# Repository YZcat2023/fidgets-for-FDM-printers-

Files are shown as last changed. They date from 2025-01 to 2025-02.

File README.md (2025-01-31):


<!-- PROJECT SHIELDS -->

<!-- PROJECT LOGO -->
<br />
<div align="center">
  <a href="https://github.com/YZcat2023/MKPSupport/blob/main/">
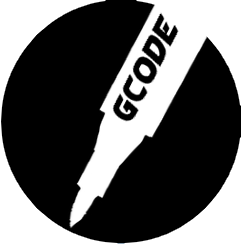
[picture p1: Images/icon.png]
    
  </a>

  <h3 align="center">MKP Support</h3>

  <p align="center">
    Better supports for FDM prints
    <br />
    <a href="https://github.com/YZcat2023/MKPSupport/blob/main/MKP%20Manual.pdf"><strong>Download MKP Manual »</strong></a>
    <br />
    <br />
  </p>
</div>

<!-- TABLE OF CONTENTS -->
<details>
  <summary>Table of Contents</summary>
  <ol>
    <li>
      <a href="#about-the-project">About The Project</a>
      <ul>
        <li><a href="#built-with">Built With</a></li>
      </ul>
    </li>
    <li><a href="#illustration">Illustration</a></li>
    <li>
      <a href="#getting-started">Getting Started</a>
      </ul>
    </li>
    <li><a href="#roadmap">Roadmap</a></li>
    <li><a href="#contributing">Contributing</a></li>
    <li><a href="#license">License</a></li>
    <li><a href="#contact">Contact</a></li>
    <li><a href="#acknowledgments">Acknowledgments</a></li>
  </ol>
</details>

<!-- ABOUT THE PROJECT -->
## About The Project
When printing parts using FDM 3D printers, supports often pose a significant challenge. They can be difficult to remove, leaving the surface of the part uneven. Therefore, reducing the layer adhesion between the support layers and the part could be a viable solution. That's why we're here—to introduce MKP Support, which delivers better results: the support surface is smooth, flat, and non-sticky, with no color difference from the main body of the part. Thanks to the incorporated function of ironing the support surface, the results may even surpass those achieved with water-soluble supports. With just four magnets, two screws, a bottle of liquid glue, and other necessary items, you can upgrade your printer. It can be run as a post-processing program in OrcaSlicer. Simply press the button, just like in the previous workflow!
<!-- FDM3D打印零件时，支撑总是一个让人头疼的问题。它们有时很难移除，移除后的零件表面也不太平整。那么，降低支撑层与零件间的层粘也许是一个好主意？试试看MKP Support吧，它能实现相当好的效果：
支撑面光滑平整不粘手，且颜色与零件主体没有区别。由于加入了熨烫支撑面的功能，也许效果比使用水溶支撑还要好。只需要四块磁铁，两个螺丝，一瓶液体胶等等，您就可以升级您的打印机。
我找来了一只马克笔涂抹支撑面，结果相当成功。接触面看上去很平滑。不过，马克笔的方案并不十分令人满意：它似乎不能在CoreXY机器上工作。于是我找来了一些 gluepen refills("点点胶替芯" in Chinese）。胶水是透明的，因此接触面效果更加好了。不过，它似乎很容易就用完了。所以我设计了一个零件用来储存胶水，并且重新编写了程序。 -->

<!-- 使用MKP Support,可以减少时间与材料的浪费
使用MKP Support,可以提高接触面的表面效果
使用MKP Support,可以提高打印的成功率 -->
Here's why:
* Using MKP Support can reduce waste of time and materials.
* Using MKP Support can enhance the surface finish of the contact area.
* Using MKP Support can increase the success rate of printing.

### Built With


  

## Illustration
Here are some printed samples. More photos may come, stay tuned!
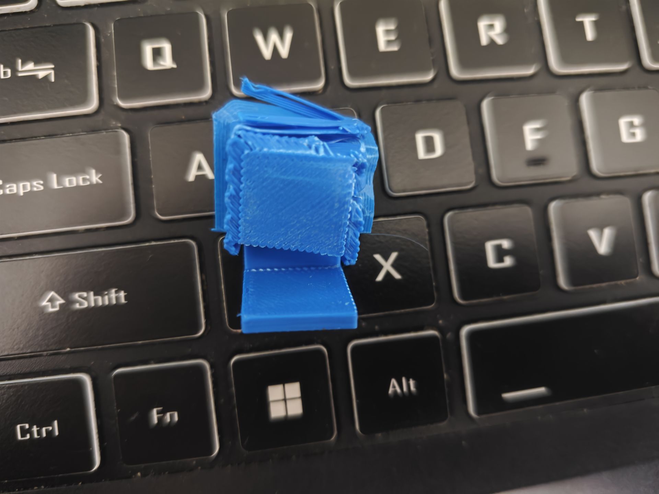
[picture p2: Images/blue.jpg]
Descriptive Alt Text


<p align="right">(<a href="#readme-top">back to top</a>)</p>

<!-- GETTING STARTED -->
## Getting Started
For more details, please refer to MKP Manual.pdf.
1.	Have some gluepen refills("点点胶替芯" in Chinese）and one bottle of liquid glue.
Get two M2.5*5 screws and four magnets with a diameter of 4mm and a thickness of 1.5mm.
2.	Download the 3D printing models provided in the folder and print them. Assemble the printed parts and install them in a proper location on your 3D printer. You may need some modification in order to suit your own printer. 
3.	Configure Settings: Run the software and fill in the required information in the dialog box. It will generate a config file. Then copy the path of MKP3.0.exe and go to your Orca Slicer settings, paste it and change several settings. If you’re using printers shipped with klipper firmware, then creating several macro is prefered.
4.	Click Slicing button and enjoy. You can also place your Gcode file in the same folder as this software and start the software. 

<!-- ROADMAP -->
## Roadmap

- [x] Ironing support interfaces option
- [x] Add MKP Manual.pdf
- [ ] Add multi-color support
- [ ] Multi-language Support
    - [ ] English

See the [open issues](https://github.com/YZcat2023/MKPSupport/issues) for a full list of proposed features (and known issues).

<p align="right">(<a href="#readme-top">back to top</a>)</p>

<!-- CONTRIBUTING -->
## Contributing
Currently, there are no other contributors on this project. We welcome anyone who would like to join!

<!-- LICENSE -->
## License

Distributed under the Unlicense License. See `LICENSE.txt` for more information.

<p align="right">(<a href="#readme-top">back to top</a>)</p>

<!-- CONTACT -->
## Contact
Jhmodel01@outlook.com
Project Link: [https://github.com/YZcat2023/MKPSupport](https://github.com/YZcat2023/MKPSupport)

<p align="right">(<a href="#readme-top">back to top</a>)</p>

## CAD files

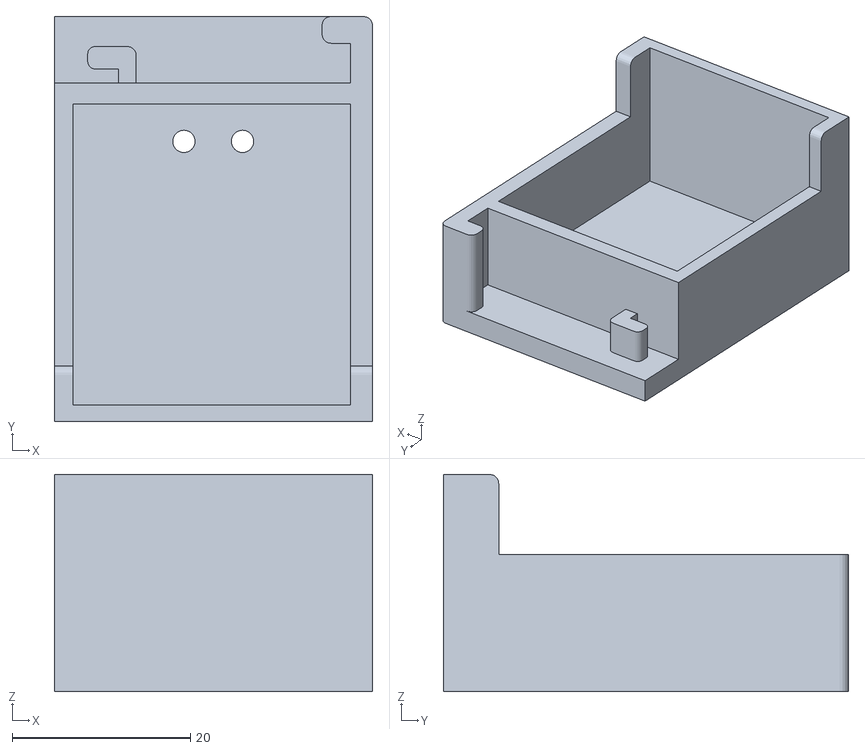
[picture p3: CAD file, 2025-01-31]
Example parts/FT_Holder_Main.stl
35.7 x 45.4 x 24.3

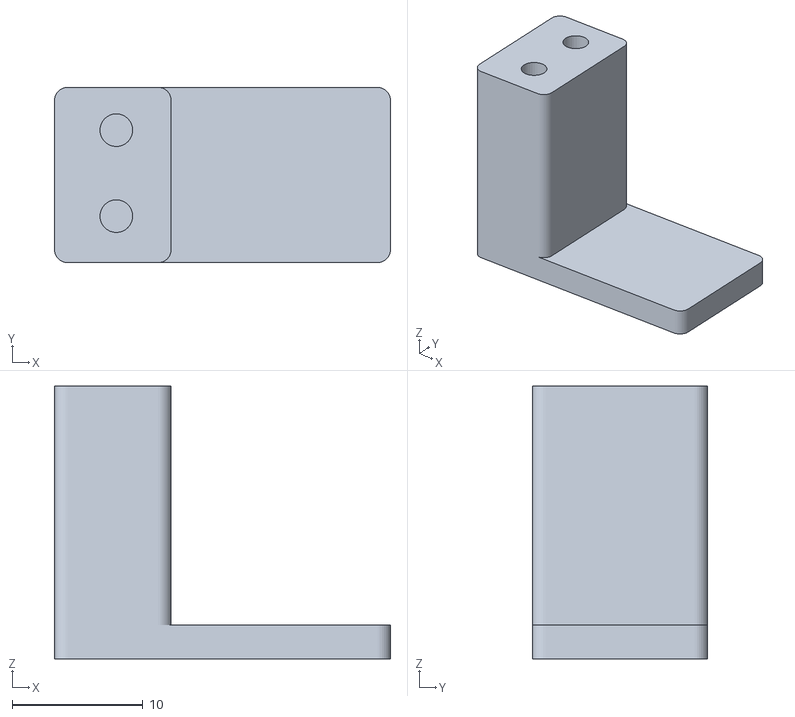
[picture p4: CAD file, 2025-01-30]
Example parts/FT_Holder_Main_part.stl
25.7 x 13.4 x 20.9

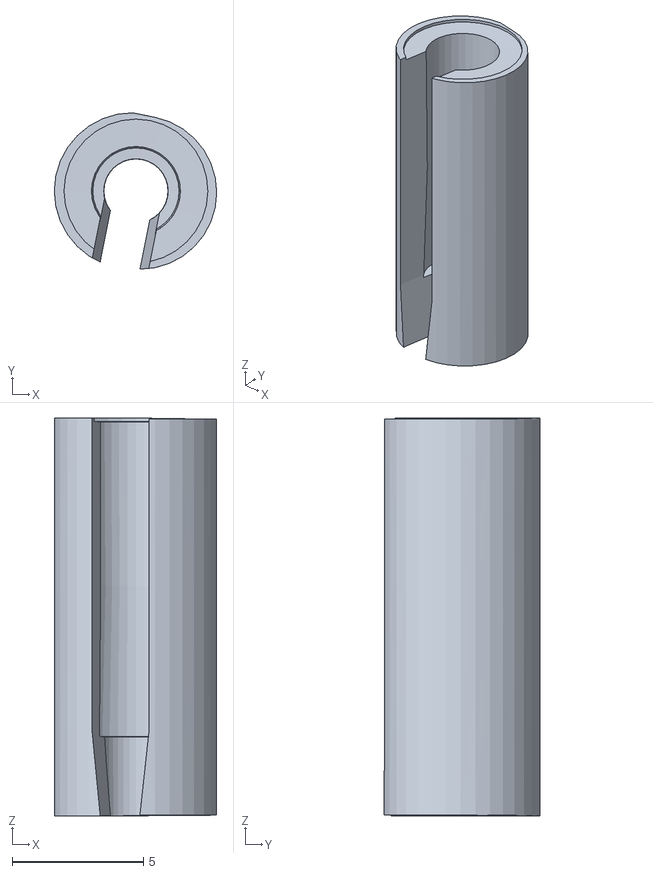
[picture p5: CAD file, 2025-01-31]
Example parts/PHold.stl
6.19 x 5.96 x 15.2

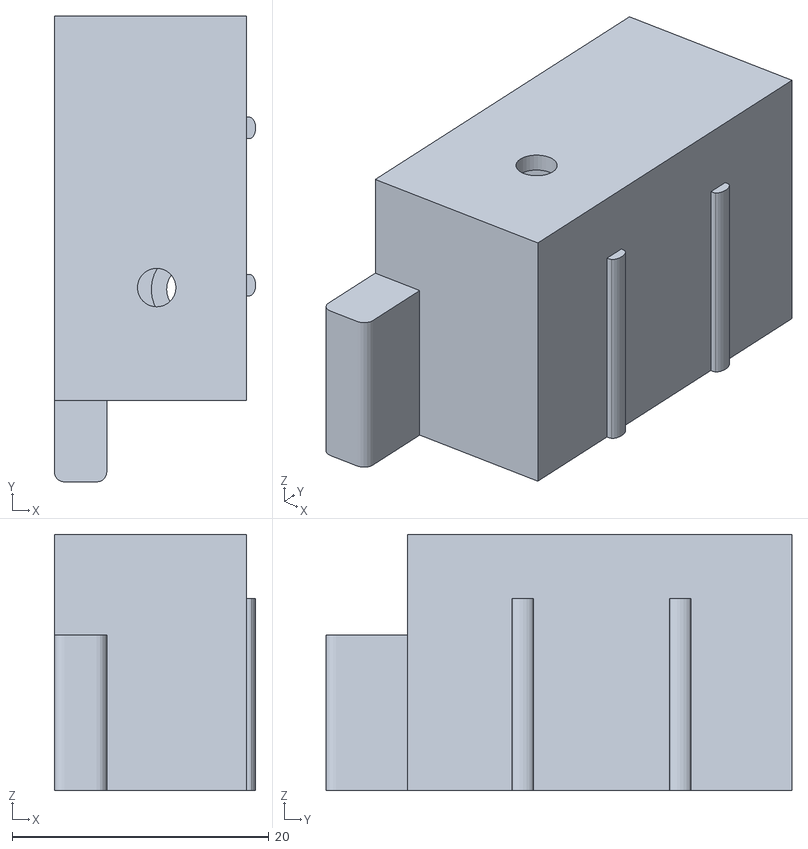
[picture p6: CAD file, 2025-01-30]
Example parts/Gluetk.stl
15.7 x 36.3 x 20.0

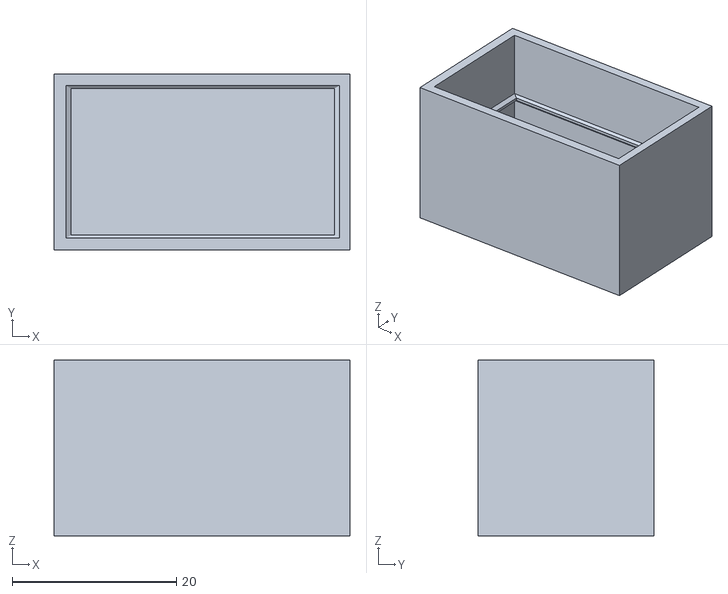
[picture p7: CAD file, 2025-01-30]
Example parts/prepare.stl
36.0 x 21.4 x 21.4

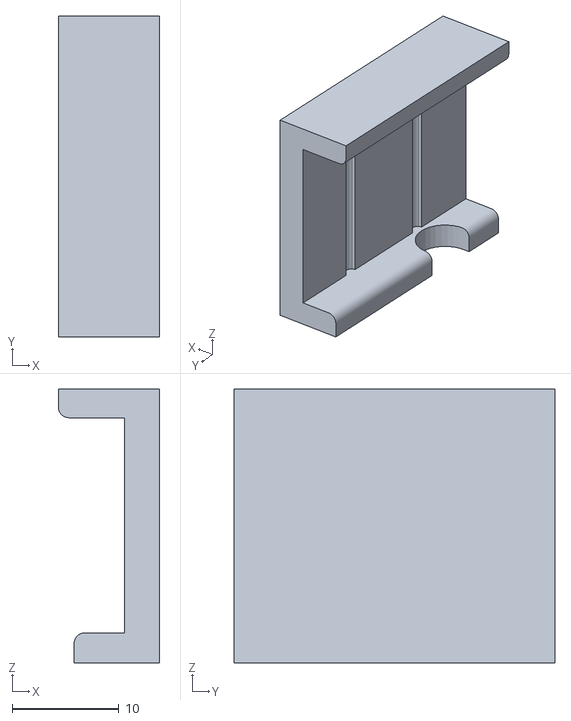
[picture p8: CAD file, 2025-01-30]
Example parts/holderTH.stl
9.47 x 30.0 x 25.6

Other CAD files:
Example parts/tk1.blend

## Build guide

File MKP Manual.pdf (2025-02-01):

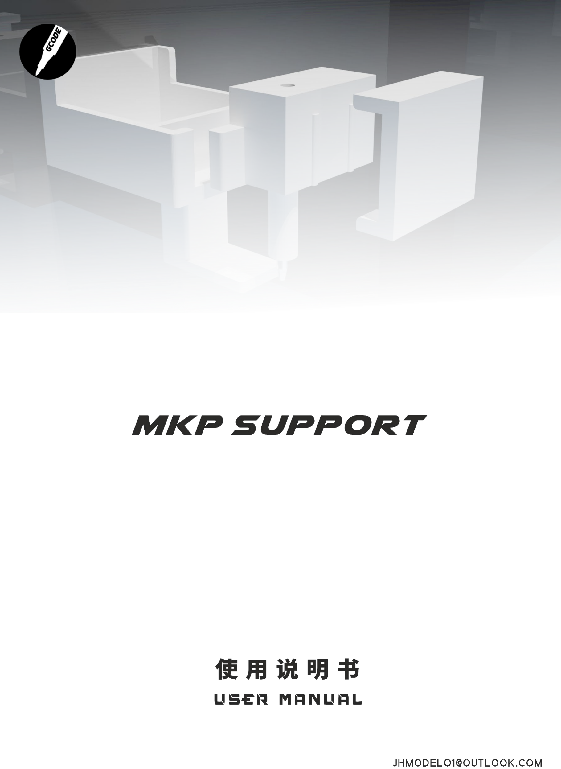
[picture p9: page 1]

2

## 目录/Contents

# 准备工作

## 1) 点点胶替芯

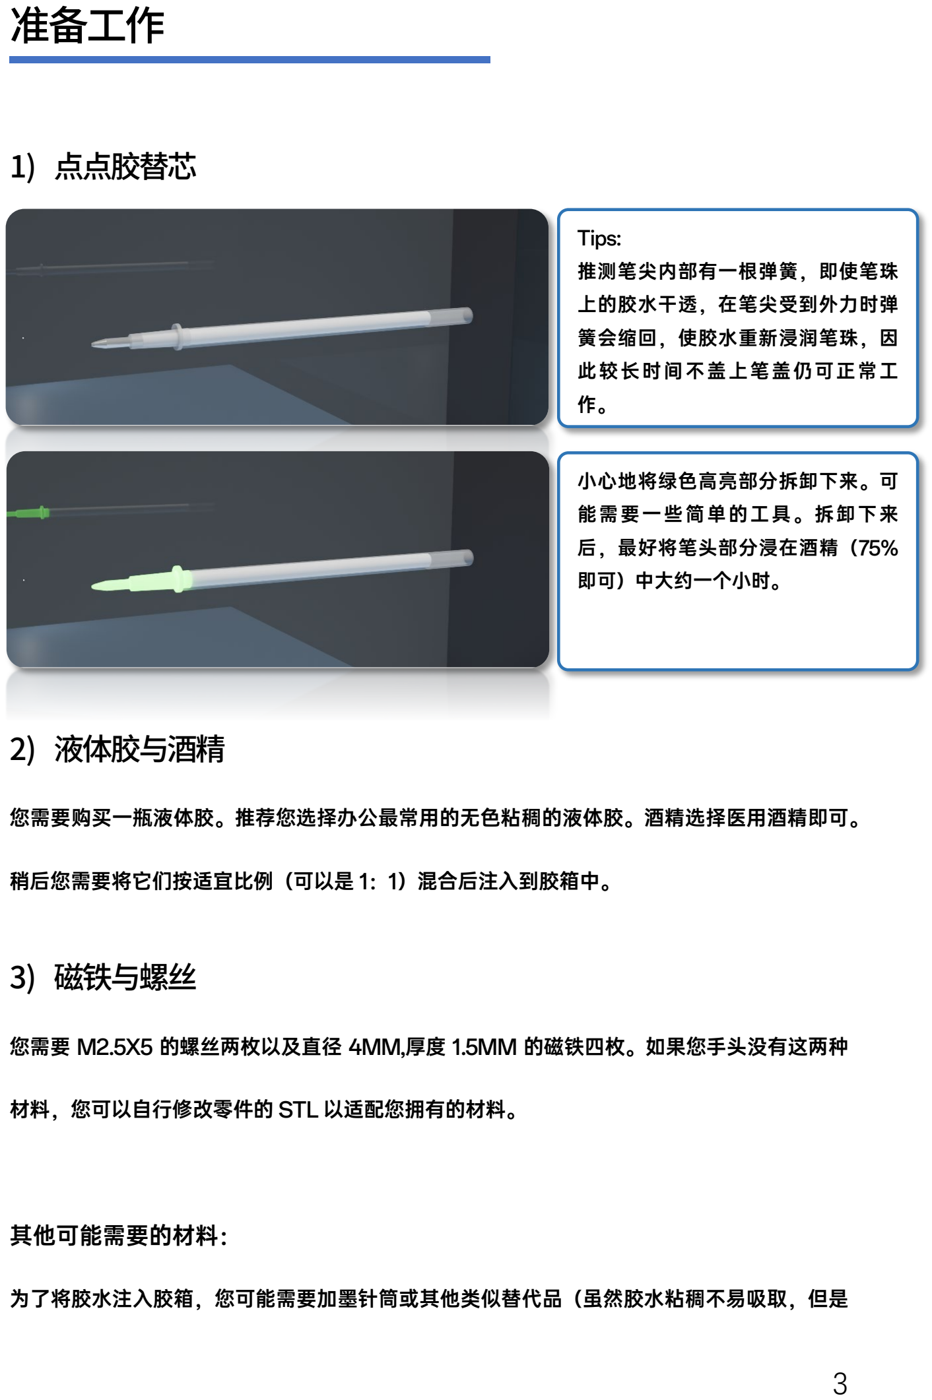
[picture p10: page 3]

3

## 2) 液体胶与酒精

您需要购买一瓶液体胶。推荐您选择办公最常用的无色粘稠的液体胶。酒精选择医用酒精即可。

稍后您需要将它们按适宜比例（可以是 1：1）混合后注入到胶箱中。

## 3) 磁铁与螺丝

您需要 M2.5X5 的螺丝两枚以及直径 4MM,厚度 1.5MM 的磁铁四枚。如果您手头没有这两种

材料，您可以自行修改零件的 STL 以适配您拥有的材料。

其他可能需要的材料：

为了将胶水注入胶箱，您可能需要加墨针筒或其他类似替代品（虽然胶水粘稠不易吸取，但是

Tips:
推测笔尖内部有一根弹簧，即使笔珠
上的胶水干透，在笔尖受到外力时弹
簧会缩回，使胶水重新浸润笔珠，因
此较长时间不盖上笔盖仍可正常工
作。

小心地将绿色高亮部分拆卸下来。可
能需要一些简单的工具。拆卸下来
后，最好将笔头部分浸在酒精（75%
即可）中大约一个小时。

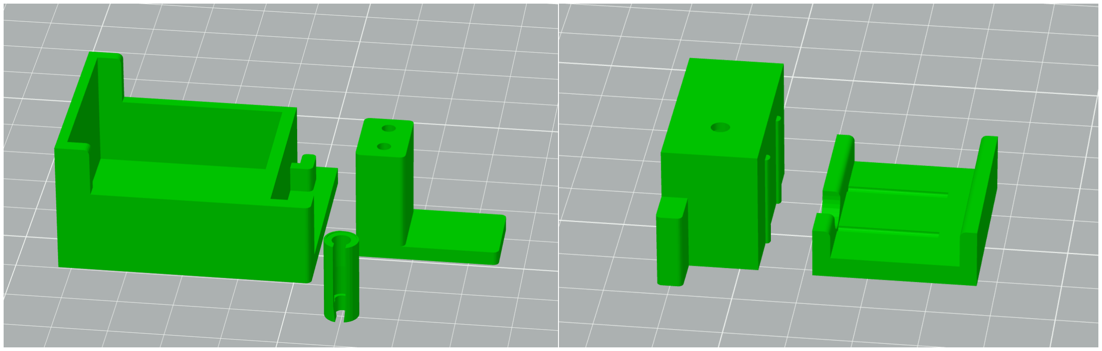
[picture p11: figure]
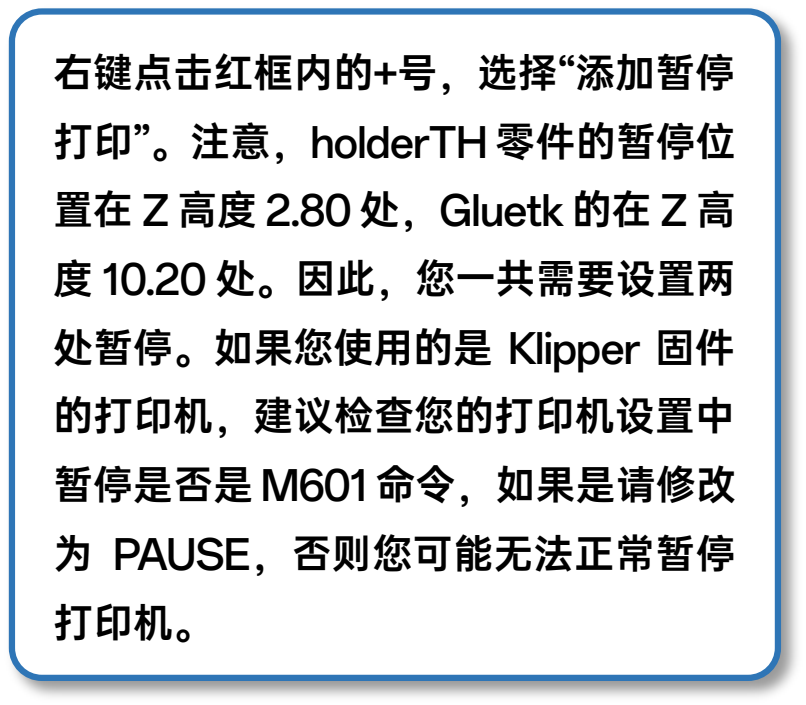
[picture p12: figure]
右键点击红框内的+号，选择“添加暂停 打印”。注意，holderTH 零件的暂停位 置在 Z 高度 2.80 处，Gluetk 的在 Z 高 度 10.20 处。因此，您一共需要设置两 处暂停。如果您使用的是 Klipper 固件 的打印机，建议检查您的打印机设置中 暂停是否是 M601 命令，如果是请修改 为 PAUSE，否则您可能无法正常暂停 打印机。

4

可以取下针后吸取，然后再装上针注入。这样操作阻力并不是很大。）安装胶箱可能需要要透

明红膜 PET 双面胶，1CM 或者更宽的。此外，一小片柔软的纸材或者布料可能是需要的，您

可以把它贴在停靠坞与笔尖接触的地方。

# 零件的打印与组装

## 1) 切片设置

推荐您按以下方式摆盘：

左侧的三个零件可以直接采用您常用的切片设置打印。

右侧的两个零件需要包埋磁铁。因此，您需要按以下操作步骤设置暂停：

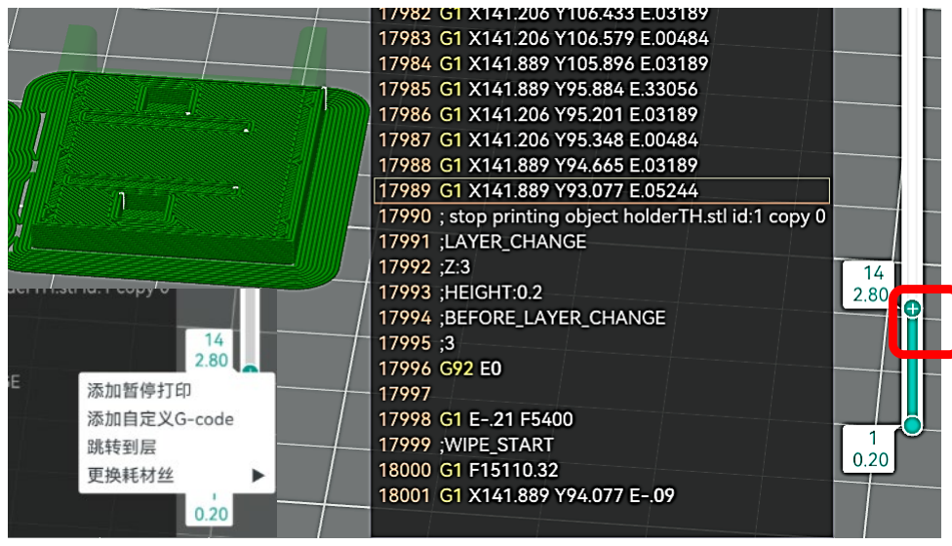
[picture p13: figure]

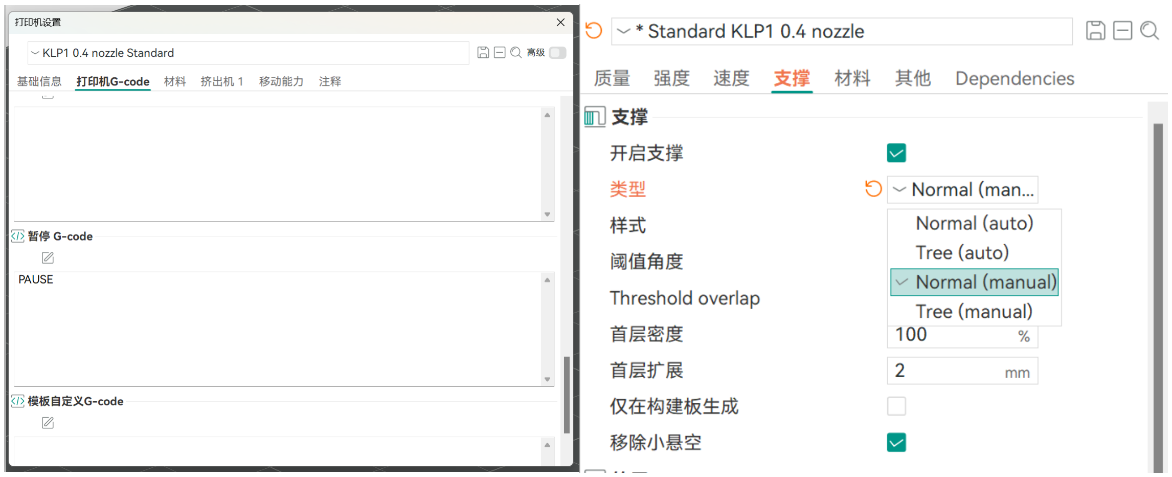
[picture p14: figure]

5

此外，需要包埋磁铁的零件请将支撑类型设置为普通（手动）,以防止软件错误生成支撑。请使

用绘制支撑功能的填充选项，将下图中绿色的面填充为支撑。

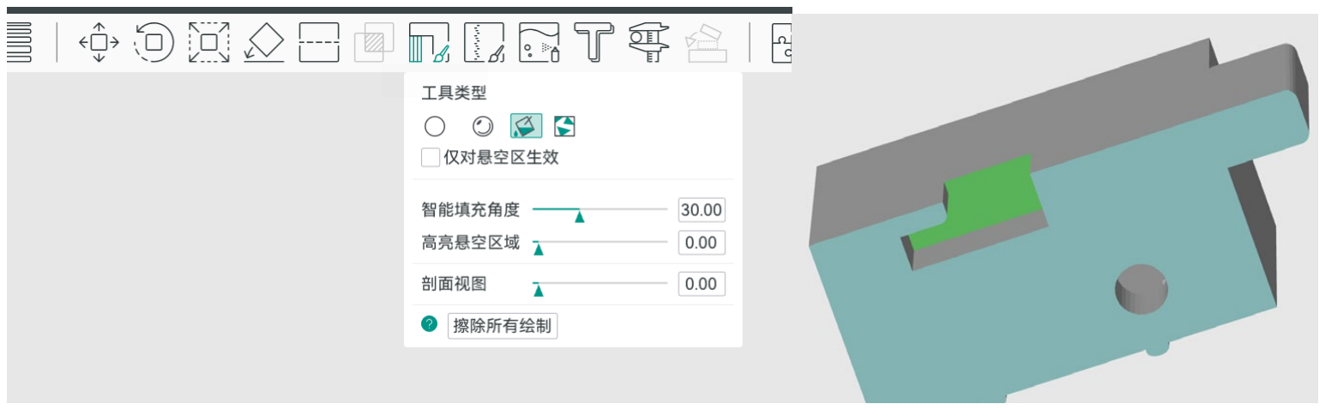
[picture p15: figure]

除此以外的其他地方请勿设置支撑。

部分打印机暂停后恢复，可能会出现由耗材渗漏引起的缺料现象。建议您添加一个立方体，然

后修改其高度为 11mm，然后将它拖拽成对象列表中的第一个，随后在打印设置中修改层内打

印顺序为按对象列表的顺序。这样，恢复之后的缺料损害会出现在这个立方体而不是零件上。

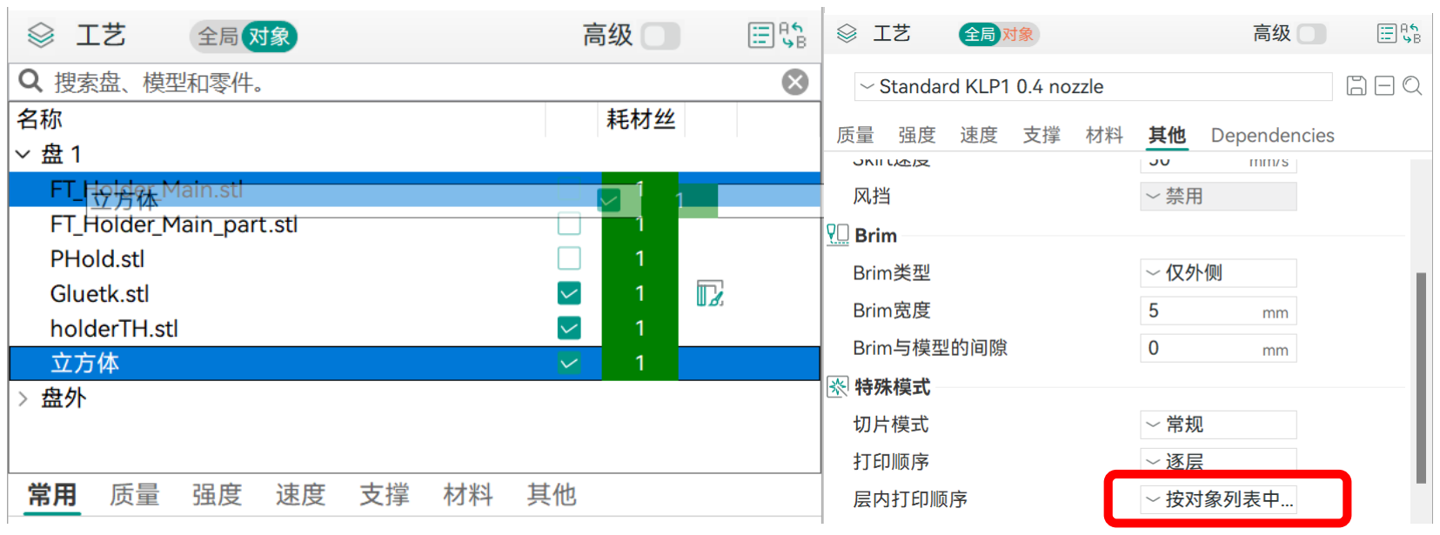
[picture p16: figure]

万事俱备，请您将文件发送打印，并在暂停时将磁铁放入空隙中，再恢复打印。建议将磁铁的

一面用记号笔涂上，以防放反。

## 2) 组装图解

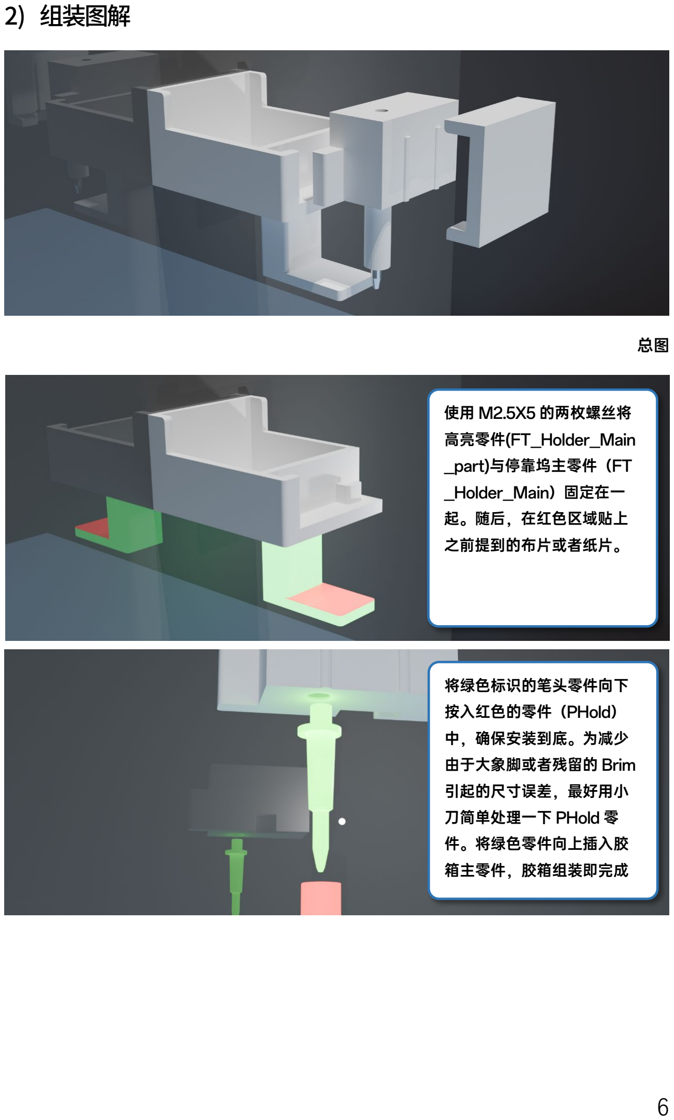
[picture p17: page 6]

6

总图

使用 M2.5X5 的两枚螺丝将
高亮零件(FT_Holder_Main
_part)与停靠坞主零件（FT
_Holder_Main）固定在一
起。随后，在红色区域贴上
之前提到的布片或者纸片。

将绿色标识的笔头零件向下
按入红色的零件（PHold）
中，确保安装到底。为减少
由于大象脚或者残留的 Brim
引起的尺寸误差，最好用小
刀简单处理一下 PHold 零
件。将绿色零件向上插入胶
箱主零件，胶箱组装即完成

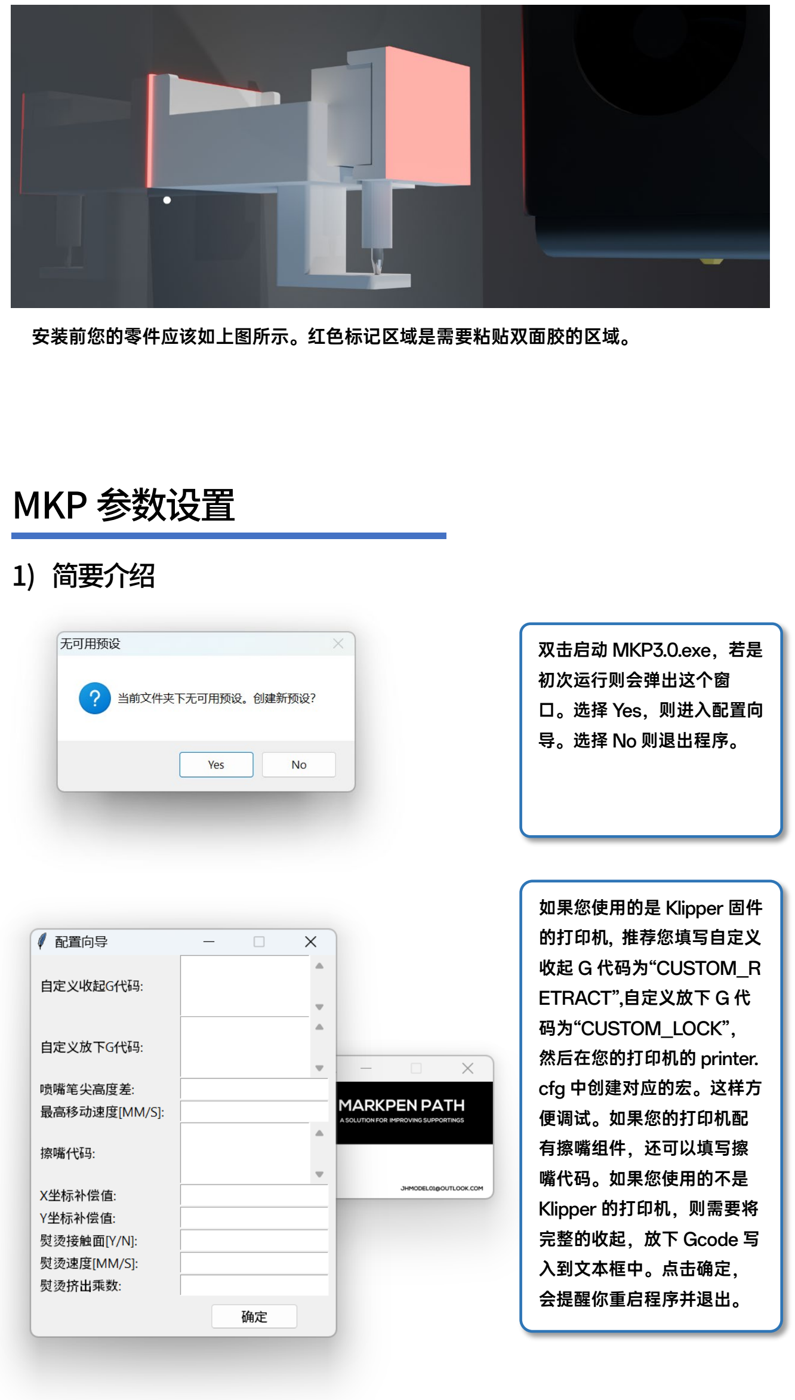
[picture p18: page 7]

7

哇啊

安装前您的零件应该如上图所示。红色标记区域是需要粘贴双面胶的区域。

# MKP 参数设置

## 1) 简要介绍

双击启动 MKP3.0.exe，若是
初次运行则会弹出这个窗
口。选择 Yes，则进入配置向
导。选择 No 则退出程序。

如果您使用的是 Klipper 固件
的打印机, 推荐您填写自定义
收起 G 代码为“CUSTOM_R
ETRACT”,自定义放下 G 代
码为“CUSTOM_LOCK”，
然后在您的打印机的 printer.
cfg 中创建对应的宏。这样方
便调试。如果您的打印机配
有擦嘴组件，还可以填写擦
嘴代码。如果您使用的不是
Klipper 的打印机，则需要将
完整的收起，放下 Gcode 写
入到文本框中。点击确定，
会提醒你重启程序并退出。

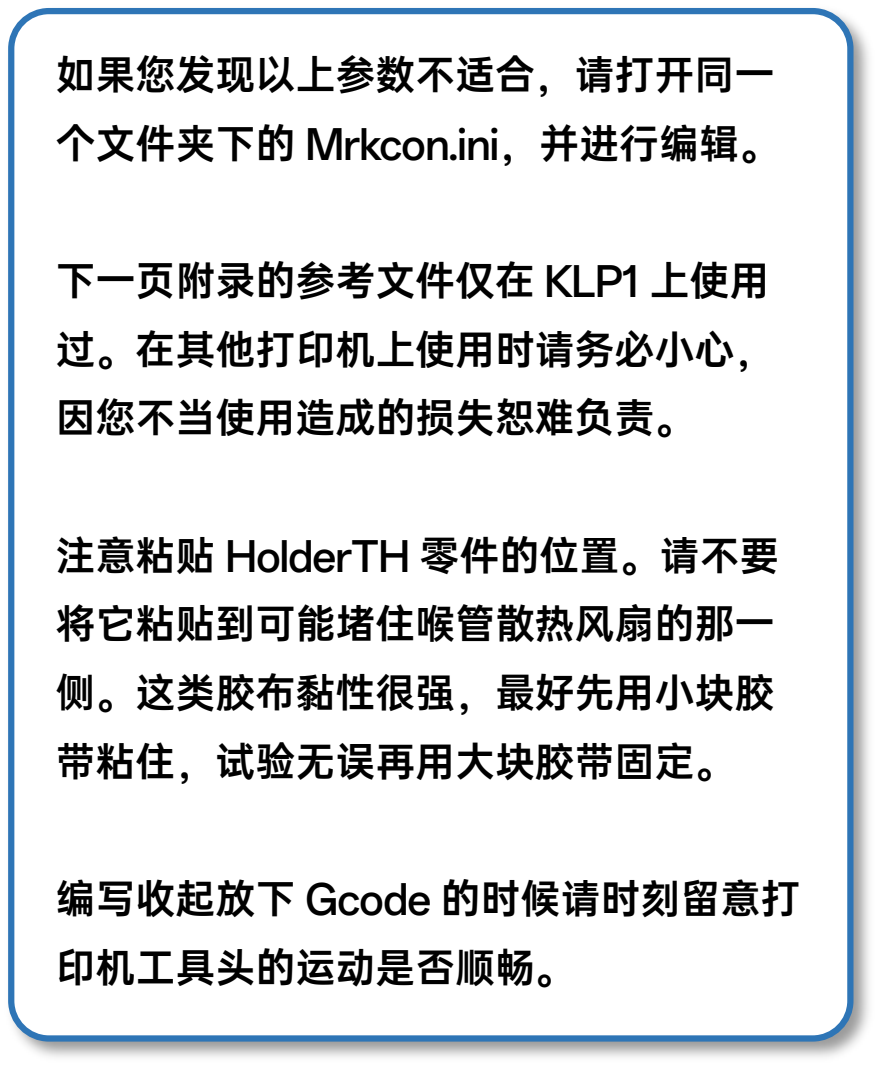
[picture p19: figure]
如果您发现以上参数不适合，请打开同一 个文件夹下的 Mrkcon.ini，并进行编辑。; 下一页附录的参考文件仅在 KLP1 上使用 过。在其他打印机上使用时请务必小心， 因您不当使用造成的损失恕难负责。; 注意粘贴 HolderTH 零件的位置。请不要 将它粘贴到可能堵住喉管散热风扇的那一 侧。这类胶布黏性很强，最好先用小块胶 带粘住，试验无误再用大块胶带固定。; 编写收起放下 Gcode 的时候请时刻留意打 印机工具头的运动是否顺畅。
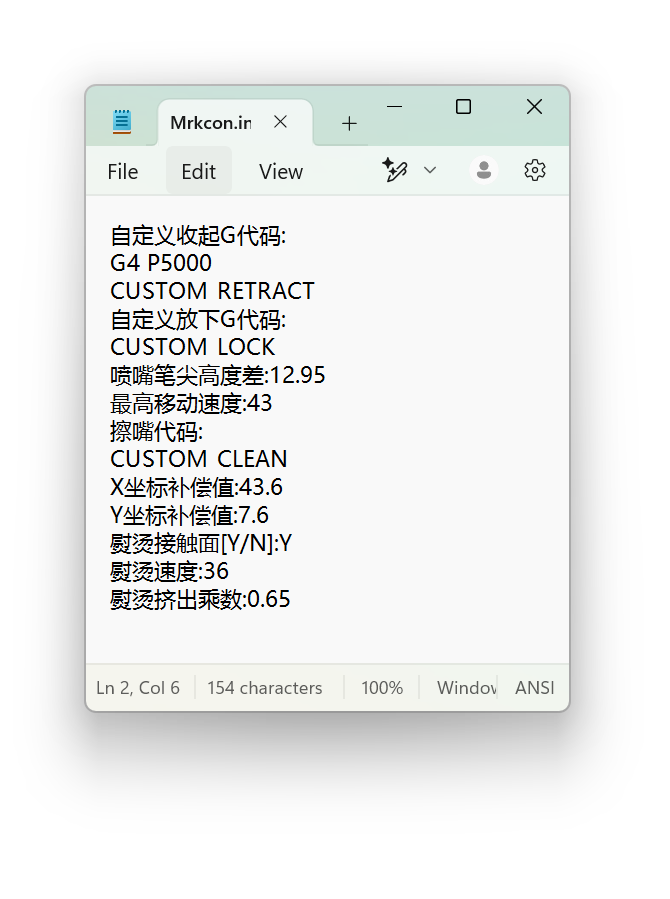
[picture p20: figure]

8

参数说明：

1. 自定义收起 G 代码：涂抹完毕之后将胶箱归位的代码。
2. 自定义放下 G 代码：将胶箱从停靠坞取下的代码。其中最好包含来回滑动数次使胶水充分

流出的代码。

3. 喷嘴笔尖高度差：挂载胶箱时，笔尖应当比喷嘴更靠近打印件。否则喷嘴会剐蹭打印件。
4. 最高移动速度：涂抹胶液时的最高速度。
5. 擦嘴代码：清理喷嘴在等待笔尖涂抹的时间内泄漏的耗材，防止缺料。
6. X,Y 坐标补偿值：喷嘴与笔尖不可能重合。那么就需要测量两者的 X，Y 差值
7. 熨烫接触面：熨烫支撑的接触面。如果填入 Y 则会启用。
8. 熨烫速度：建议设置成比常用的实心面熨烫速度稍微快一点的速度。
9. 熨烫挤出乘数：熨烫不需要与正常打印的挤出流量相同，不过，它与普通打印的熨烫流量

也不同（大概在 0.6 左右）

## 2) 修改 Mrkcon.ini

9

附录：Printer.cfg 中 CUSTOM_LOCK 与 CUSTOM_RELEASE 的宏示例

[gcode_macro CUSTOM_LOCK]
gcode:
;CustomLock
G1 E-7
G92 E0
G1 F18000
G1 X10
G1 Y204.2
G1 X0.1
G1 F3000
G1 Y208
G1 Y204.2
G1 Y208
G1 Y204.2
G1 Y208
G1 Y204.2
G1 Y208
G1 Y204.2
G1 Y208
G1 X10
G1 Y160

[gcode_macro CUSTOM_RETRACT] gcode:
;CustomRetract
G1 E7
G92 E0
G1 F18000
G1 X10
G1 Y208
G1 F3000
G1 X0.1
G1 Y204.2
G1 X10
G1 F18000
G1 Y160
G1 F3600

# OrcaSlicer 参数设置

## 1) 打印机设置

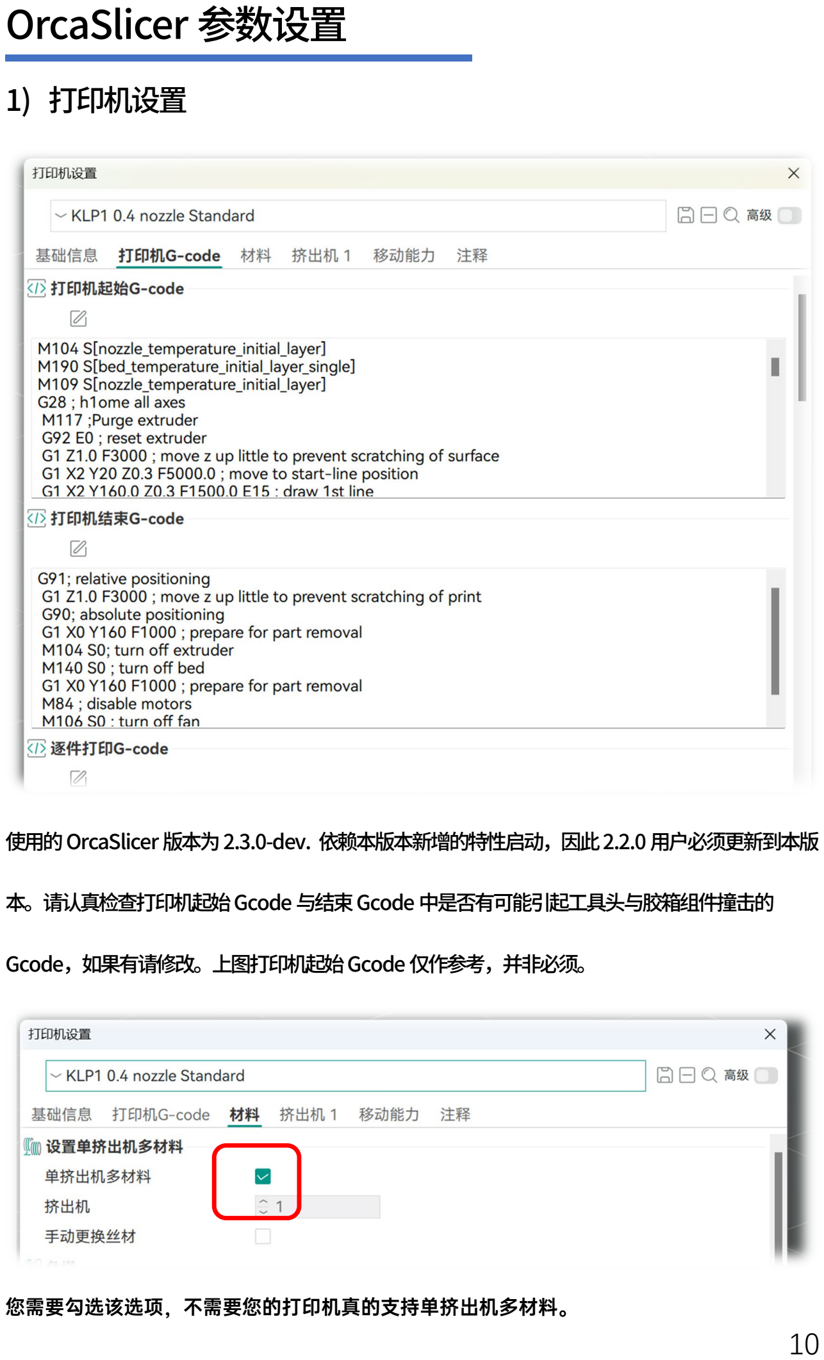
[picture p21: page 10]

10

使用的OrcaSlicer 版本为2.3.0-dev. 依赖本版本新增的特性启动，因此2.2.0 用户必须更新到本版

本。请认真检查打印机起始Gcode 与结束Gcode 中是否有可能引起工具头与胶箱组件撞击的

Gcode，如果有请修改。上图打印机起始Gcode 仅作参考，并非必须。

您需要勾选该选项，不需要您的打印机真的支持单挤出机多材料。

## 2) 耗材设置

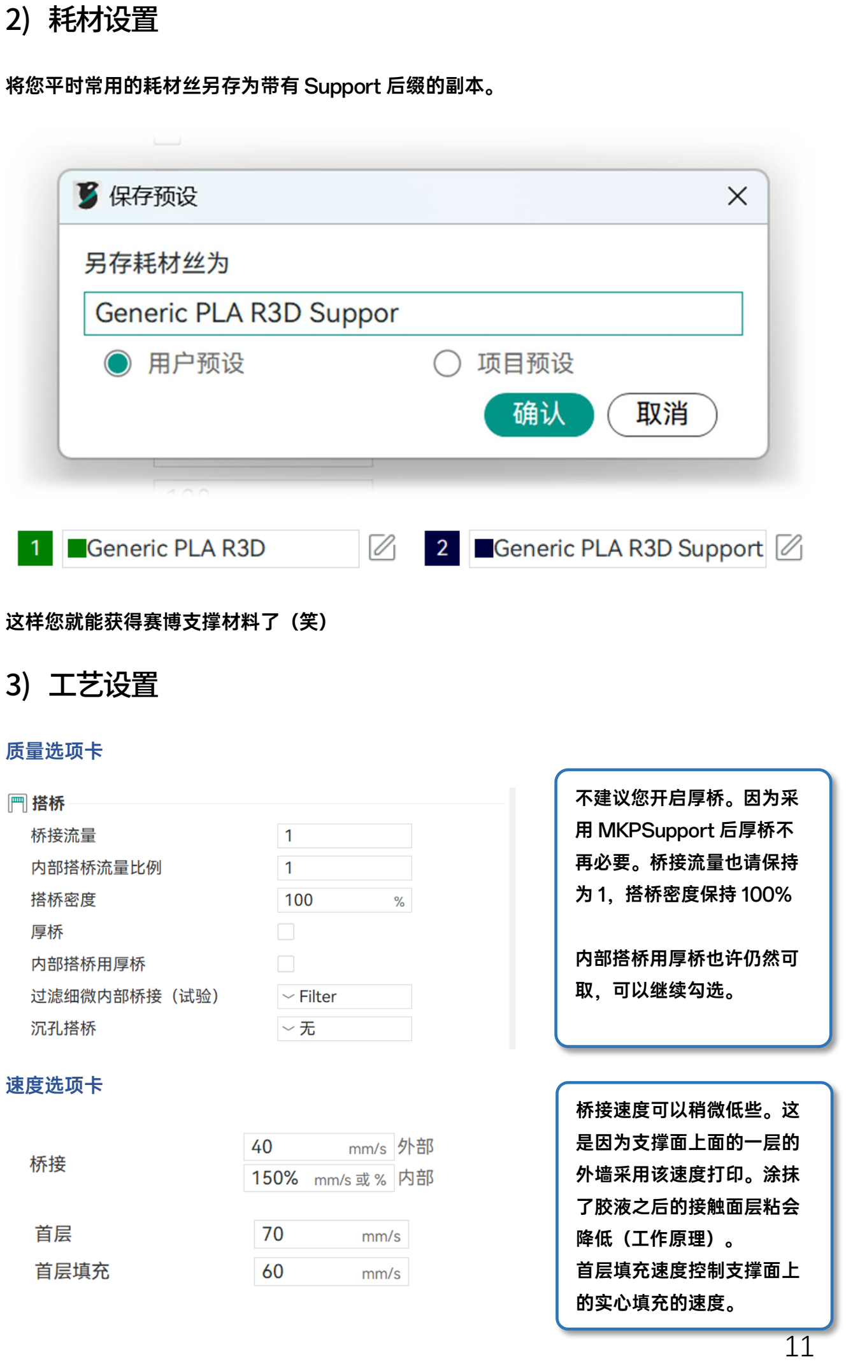
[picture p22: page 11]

11

将您平时常用的耗材丝另存为带有 Support 后缀的副本。

这样您就能获得赛博支撑材料了（笑）

## 3) 工艺设置

质量选项卡

速度选项卡

不建议您开启厚桥。因为采
用 MKPSupport 后厚桥不
再必要。桥接流量也请保持
为 1，搭桥密度保持 100%

内部搭桥用厚桥也许仍然可
取，可以继续勾选。

桥接速度可以稍微低些。这
是因为支撑面上面的一层的
外墙采用该速度打印。涂抹
了胶液之后的接触面层粘会
降低（工作原理）。
首层填充速度控制支撑面上
的实心填充的速度。

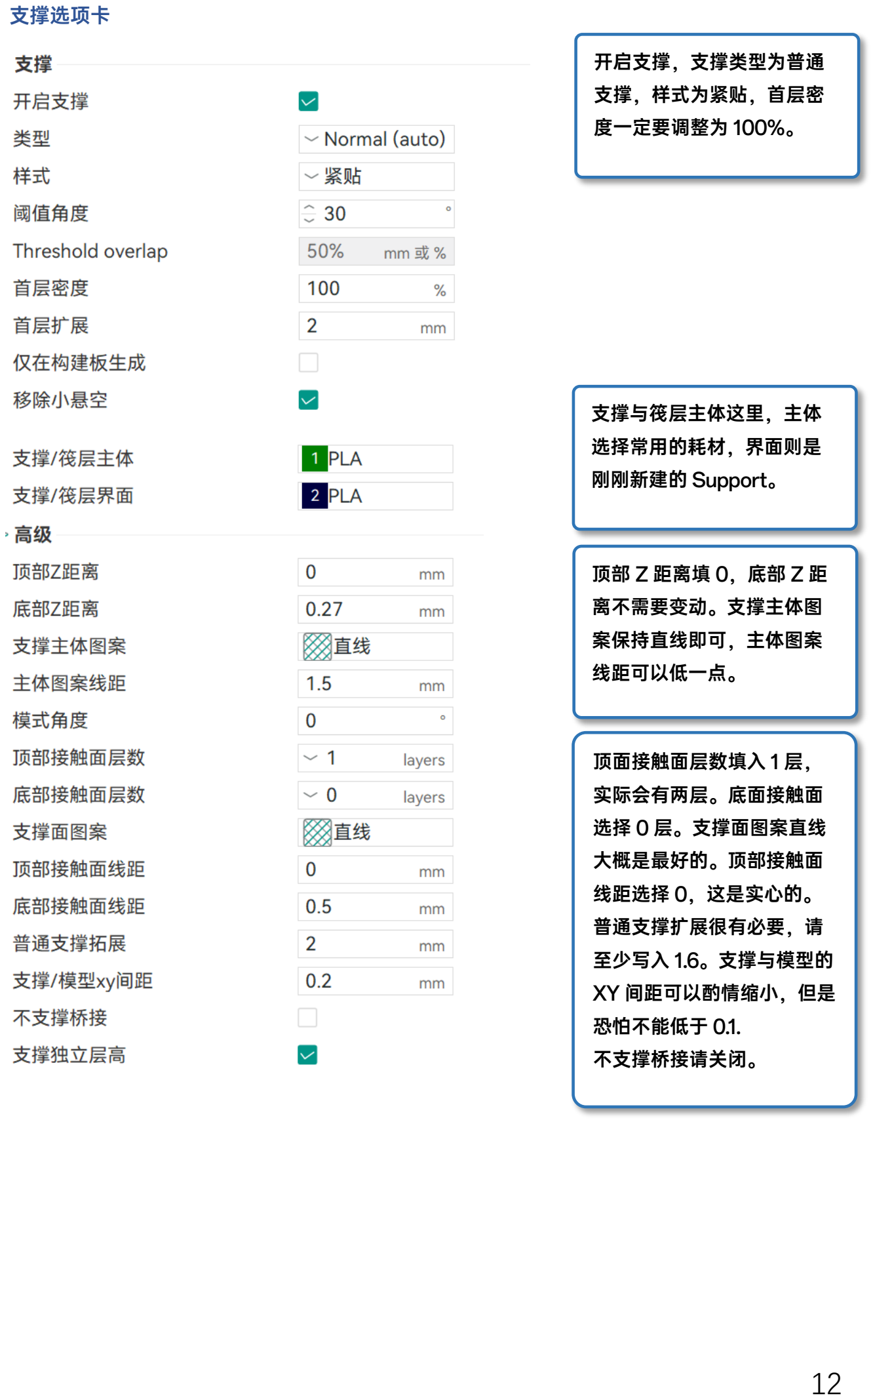
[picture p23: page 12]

12

支撑选项卡
开启支撑，支撑类型为普通
支撑，样式为紧贴，首层密
度一定要调整为 100%。

支撑与筏层主体这里，主体
选择常用的耗材，界面则是
刚刚新建的 Support。

顶部 Z 距离填 0，底部 Z 距
离不需要变动。支撑主体图
案保持直线即可，主体图案
线距可以低一点。

顶面接触面层数填入 1 层，
实际会有两层。底面接触面
选择 0 层。支撑面图案直线
大概是最好的。顶部接触面
线距选择 0，这是实心的。
普通支撑扩展很有必要，请
至少写入 1.6。支撑与模型的
XY 间距可以酌情缩小，但是
恐怕不能低于 0.1.
不支撑桥接请关闭。

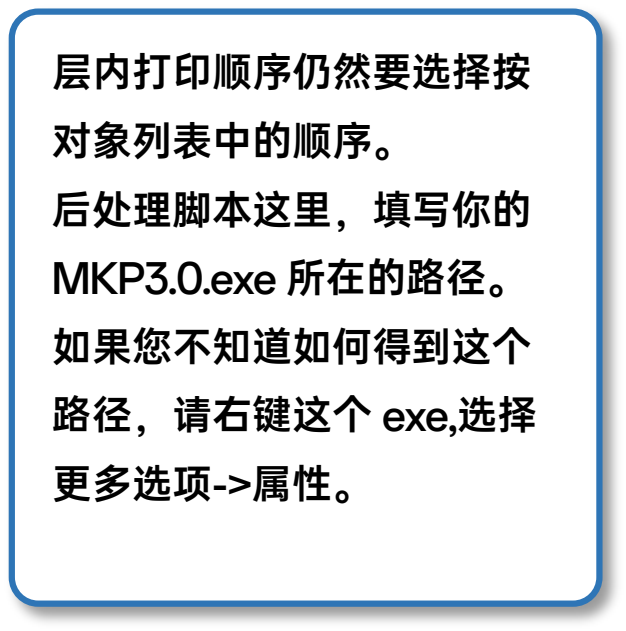
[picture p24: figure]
层内打印顺序仍然要选择按 对象列表中的顺序。 后处理脚本这里，填写你的 MKP3.0.exe 所在的路径。 如果您不知道如何得到这个 路径，请右键这个 exe,选择 更多选项->属性。
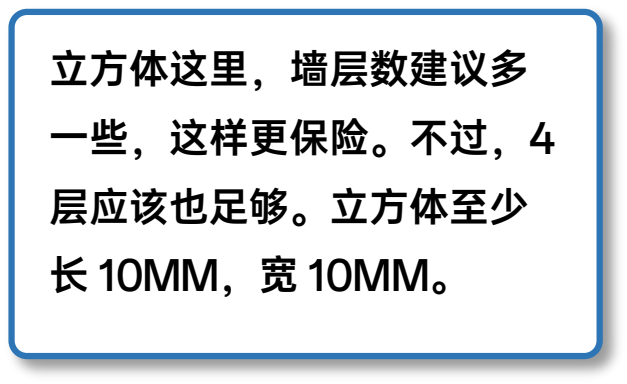
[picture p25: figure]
立方体这里，墙层数建议多 一些，这样更保险。不过，4 层应该也足够。立方体至少 长 10MM，宽 10MM。

13

其他选项卡

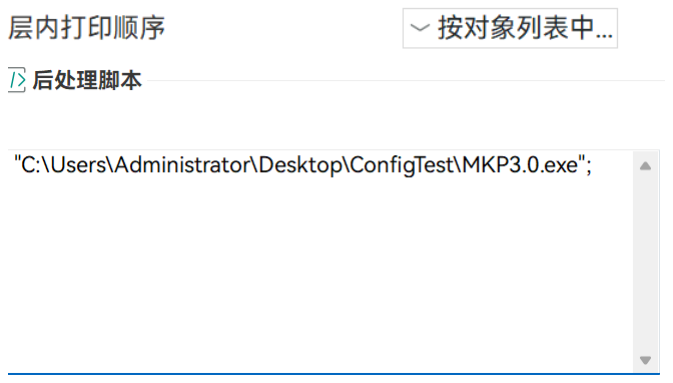
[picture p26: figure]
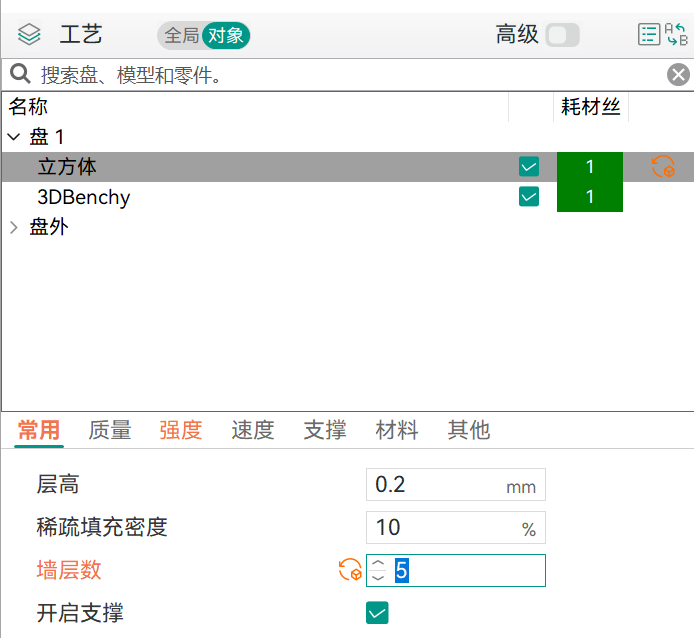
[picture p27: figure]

# 参数的微调

## 1) X,Y 补偿值与喷嘴笔尖高度差的调整

建议在热床上粘上一张小纸片，上面点上点，然后移动工具头使得喷嘴移动到点上。随后，请

挂载胶箱。并移动工具头使得笔尖移动到点上方。记录这两次工具头 X,Y 坐标的差值，即可计

算出 X,Y 的偏移值。随后，可以先将最高移动速度改低一些，然后观察是否刚好涂抹准确。若

不准确再行细调。

14

微调喷嘴笔尖高度差时，请先回零，然后将 Z 的数值设置成 30，挂载胶箱，然后逐步降低 Z

高度直到笔尖几乎接触到热床。然后填入数据，运行一次，检查是否涂上。若已经涂上，则

升高 0.1MM.看看是否仍能涂上，若不能则减低 0.1MM，调整直到恰好可以涂抹为止。

致谢

本项目在开发过程中依赖了以下软件和工具等，特此声明并感谢它们的开发者：

1. OrcaSlicer. 特别感谢 Orcaslicer 团队为我们提供了如此强大且用户友好的 3D 打印切片

软件。我们深感荣幸能够使用这样一款优秀的软件，并对 Orcaslicer 团队的辛勤工作和无

私奉献表示最诚挚的感谢。

2. OPPO Sans 字体.这是一款简洁真实、富有科技美感的字体。
3. Iconian Fonts 的数款字体。这些字体设计感突出，线条流畅，风格独特，为我们的说明

书封面增添了相当的艺术美感。

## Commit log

2024-08-12 Delete Fixer for Aquila C2 v1.2.stl
    Obsolete for using
    [Fixer for Aquila C2 v1.2.stl]
2024-08-12 Delete fixer.stl
    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
    [fixer.stl]
2024-08-12 Delete l directory
    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
    [addon.stl, base.stl, cover.stl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]
2024-08-12 Delete trigger.stl
    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
    [trigger.stl]
2025-01-30 Remove since they're obsolete.
    [Cali.stl]
2025-01-30 new files
    [FT_Holder_Main.stl, FT_Holder_Main_part.stl, Gluetk.stl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]
2025-01-31 STL fixed
    [FT_Holder_Main.stl, PHold.stl]
